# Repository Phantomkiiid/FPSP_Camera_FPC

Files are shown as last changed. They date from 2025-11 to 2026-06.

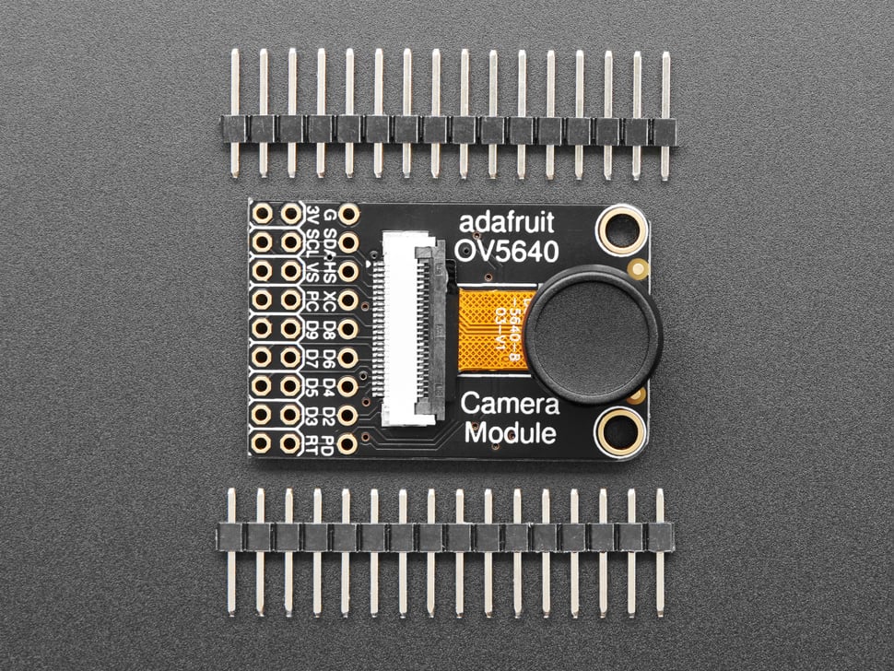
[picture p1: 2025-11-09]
docs/Adafruit-OV5640-Camera-Breakout-PCB-main/assets/5673-06.jpg

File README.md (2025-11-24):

# FPSP_Camera_FPC
This repo contains FPC schematics of the newly developed FPSP camera project on an FPC board, aiming for super-high-speed parallel image processing.

## Repository Structure
| Directory | Use |
| --- | --- |
| archive_old/ | Archived initial design (**not working**) |
| custom_fp/ | Footprint from external libraries |
| docs/ | Documentation gathered from external sources |

## TODO
- [ ] RP2350 Power Supply Layout
- [ ] Add Proper Power Sequencing
- [ ] Source RP2354 A4
- [ ] Source B2B Connector
- [ ] B2B Connector Pinout + Layout
- [ ] HSTX Layout

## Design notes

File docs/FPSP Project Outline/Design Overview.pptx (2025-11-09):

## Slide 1

Design Overview: one processing unit

Industrial CMOS sensor

(front-end integrated)

Options:
Sony: IMX273 / IMX287
OnSemi: python series
Teledyne: EV76C560 / EV76C570

one “pixel”

Vdd

MSPM0C1104 microcontroller

comp flag

global I/O

registers

enable flag

E

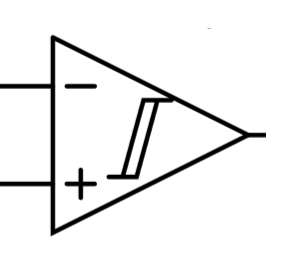
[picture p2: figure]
enter image description here

neighbour I/O & register values

A/D bus

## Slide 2

Design Overview: overall architecture

pixel unit

pixel processor

N pixels

···

···

···

···

···

···

Pixel array

···

···

N pixels

Himax HX6537-A
Pixel Array Microprocessor

···

···

A/D bus 1

···

A/D bus k

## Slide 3

Model | Resolution (pixels) | Pixel Size (µm) | Optical Format | Max Frame Rate (fps) | Output Interface(s) | Notes
Sony IMX273 | 1456 × 1088 (~1.58 MP) | 3.45 × 3.45 | 1/2.9″ (~6.3 mm) | ~226.5 (10-bit mode) | Sub-LVDS / MIPI (varies) | Low-noise, high-speed, common in inspection
Sony IMX287 | 728 × 544 (~0.4 MP) | 6.9 × 6.9 | 1/2.9″ (~6.3 mm) | ~436.9 (10-bit mode) | Sub-LVDS / MIPI (varies) | Large pixels, high sensitivity, good in NIR / low light
OnSemi PYTHON1300 | 1280 × 1024 (1.3 MP) | 4.8 × 4.8 | 1/2″ | ~210 (LVDS) / ~43 (parallel) | LVDS (multi-lane) / parallel | supports ROI, programmable gain, CDS.
OnSemi PYTHON5000 | 2592 × 2048 (~5.3 MP) | 4.8 × 4.8 | ~1″ | Up to ~100 (Zero ROT mode) | LVDS (e.g., 8-lane) | Higher resolution, suited for machine vision with high data bandwidth.
Teledyne EV76C560 | 1280 × 1024 (1.31 MP) | 5.3 × 5.3 | 1/1.8″ | ~60 full res (VGA/cropped >100) | Parallel 10-bit | Dual shutter modes, WDR/HDR, ROI, defect correction.
Teledyne EV76C570 | 1600 × 1200 (~2.0 MP) | 4.5 × 4.5 | 1/1.8″ | ~50 full res | Parallel 10-bit | 2 MP variant, good low-light and dynamic range features.

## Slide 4

Design Overview: overall architecture v2.0

OV5640

···

FPC

DVP

PIO

···

RP2354A

Inter-FPC connection

Strengthened FPC

Pin Header

FPGA board
(pynq / zynq)

PL: data receive
PS: data process

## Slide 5

Layout Overview

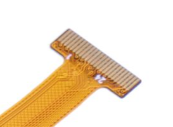
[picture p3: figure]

Main FPC

Strengthened FPC

BUCK/LDO

Pin Header to FPGA

OV5640
(front)

ZIF Connector

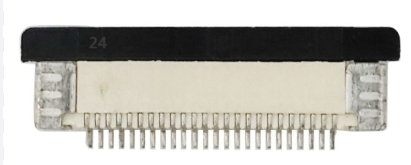
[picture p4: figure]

Vin

···

···

RP2354A
(back)

ASM330LHH
(back)

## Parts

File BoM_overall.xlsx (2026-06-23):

Part Name | Series Number / Description | Quantity | Source | Unit Price (GBP) | Order Code / Mouser No | Link
USB_B_Micro | USB_Micro-B_Molex_47346-0001 | 5 | Farnell | 1.2 | 1568026 | https://uk.farnell.com/molex/47346-0001/micro-usb-conn-2-0-type-b-r-a/dp/1568026
Conn_02x07_Counter_Clockwise | Molex_SlimStack_502426-1430_2x07_P0.40mm_Vertical | 10 | Farnell | 0.868 | 3500584 | https://uk.farnell.com/molex/502426-1430/mezzanine-conn-rcpt-14pos-2row/dp/3500584
Conn_02x07_Counter_Clockwise | Molex_SlimStack_502430-1430_2x07_P0.40mm_Vertical | 10 | Farnell | 0.465 | 3911710 | https://uk.farnell.com/molex/502430-1430/mezzanine-conn-hdr-14pos-2row/dp/3911710
Switch (slide) | CAS-120TA1 | 10 | Farnell | 1.1832 | 2854716 | https://uk.farnell.com/nidec-copal-electronics/cas-120ta/slide-switch-spdt-0-1a-6vdc-smd/dp/2854716
Push Button | PTS526SM15SMTR2 LFS | 10 | Mouser | 0.12 | 611-PTS526SM15SMTR2L | https://www.mouser.co.uk/ProductDetail/CK/PTS526SM15SMTR2-LFS?qs=Imq1NPwxi75LpUh6FiCy2w%3D%3D
SM03B-SRSS-TB | JST_SH_SM03B-SRSS-TB_1x03-1MP_P1.00mm_Horizontal | 5 | Farnell | 0.52 | 1679118 | https://uk.farnell.com/stmicroelectronics/lsm6dsltr/inemo-inertial-module-2-4-8-16g/dp/2761748
IMU | LSM6DSLTR | 5 | Farnell | 7.884 | 4572492 | https://uk.farnell.com/tdk/icm-45686/mems-module-6-axis-1-71v-3-6v/dp/4572492
LDO | TLV73315PDRV | 5 | Mouser | 0.44 | 595-TLV73315PQDRVRQ1 | https://www.mouser.co.uk/ProductDetail/Texas-Instruments/TLV73315PQDRVRQ1?qs=Euq2YPj5ArIsMkihzFWY8w%3D%3D
MCU | RP2354A | 5 | Mouser | 0.751 | 358-SC151113 | https://www.mouser.co.uk/ProductDetail/Raspberry-Pi/SC151113-A4?qs=4dK74SdgGtxoqGOrTUEtvA%3D%3D
Mems | SiT8008BI-13-33E-12.000000G | 5 | Mouser | 0.721 | 788-8008BI1333E12G | https://www.mouser.co.uk/ProductDetail/SiTime/SiT8008BI-13-33E-12.000000G?qs=dMZC7um9hO8fSmv9H8HgEQ%3D%3D
FPC socket | molex 52435-2471 | 10 | Farnell | 2.352 | 2396220 | https://uk.farnell.com/molex/52435-2471/connector-ffc-fpc-24pos-1row-0/dp/2396220
Camera | OV5640 - 24pin fpc | 2 | Ali | N/A | N/A | https://www.aliexpress.com/p/tesla-landing/index.html?UTABTest=aliabtest125094_24784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
2.54mm pin header: from UCL
0603 R&C: from UCL

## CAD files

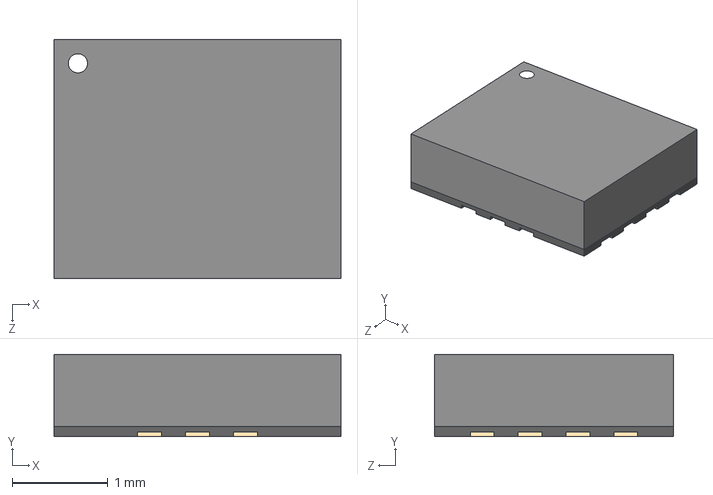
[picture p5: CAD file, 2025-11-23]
custom_fp/ICM_45686/ICM-45686.step
3.00 x 0.86 x 2.50 mm

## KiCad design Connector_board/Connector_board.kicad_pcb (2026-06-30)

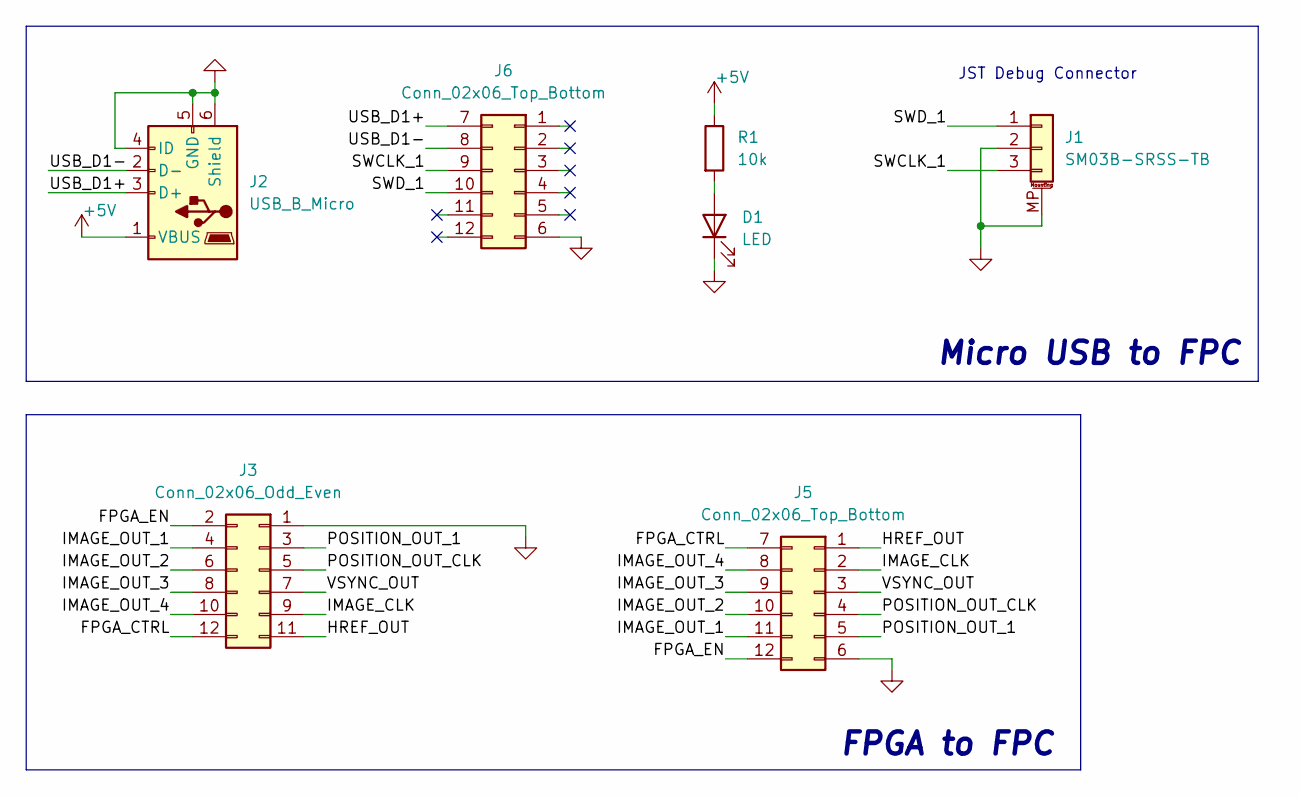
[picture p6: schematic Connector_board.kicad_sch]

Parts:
D1: LED; D_0603_1608Metric
J1: SM03B-SRSS-TB; JST_SH_SM03B-SRSS-TB_1x03-1MP_P1.00mm_Horizontal
J2: USB_B_Micro; USB_Micro-B_Molex_47346-0001
J3: Conn_02x06_Odd_Even; PinHeader_2x06_P2.54mm_Vertical
J5, J6: Conn_02x06_Top_Bottom; CON_5035521222
R1: 10k; R_0603_1608Metric_Pad0.98x0.95mm_HandSolder

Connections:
+5V: J2.1 (VBUS), R1.1
/FPGA_CTRL: J3.12, J5.7
/FPGA_EN: J3.2, J5.12
/HREF_OUT: J3.11, J5.1
/IMAGE_CLK: J3.9, J5.2
/IMAGE_OUT_1: J3.4, J5.11
/IMAGE_OUT_2: J3.6, J5.10
/IMAGE_OUT_3: J3.8, J5.9
/IMAGE_OUT_4: J3.10, J5.8
/POSITION_OUT_1: J3.3, J5.5
/POSITION_OUT_CLK: J3.5, J5.4
/SWCLK_1: J1.3, J6.9
/SWD_1: J1.1, J6.10
/USB_D1+: J2.3 (D+), J6.7
/USB_D1-: J2.2 (D-), J6.8
/VSYNC_OUT: J3.7, J5.3
GND: D1.1 (K), J1.2, J1.MP (MountPin), J2.4 (ID), J2.5 (GND), J2.6 (Shield), J3.1, J5.6, J6.6
unnamed: D1.2 (A), R1.2

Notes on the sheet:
FPGA to FPC
Micro USB to FPC
JST Debug Connector

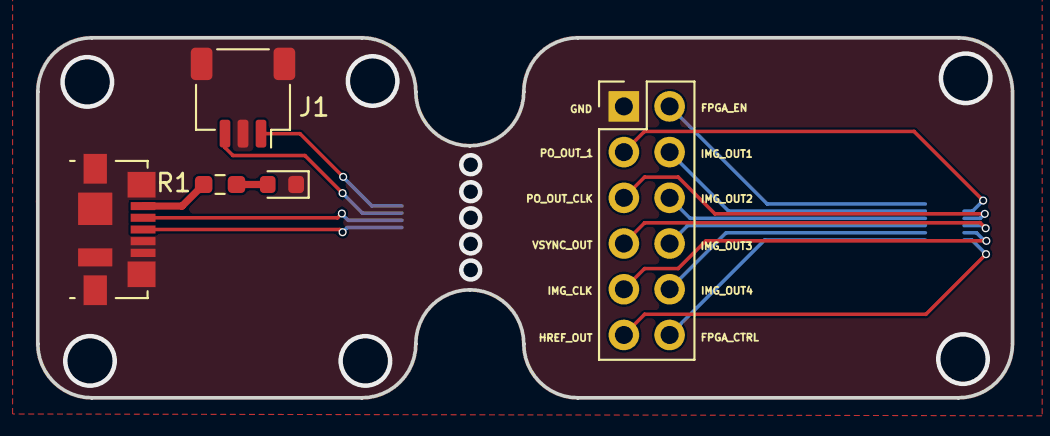
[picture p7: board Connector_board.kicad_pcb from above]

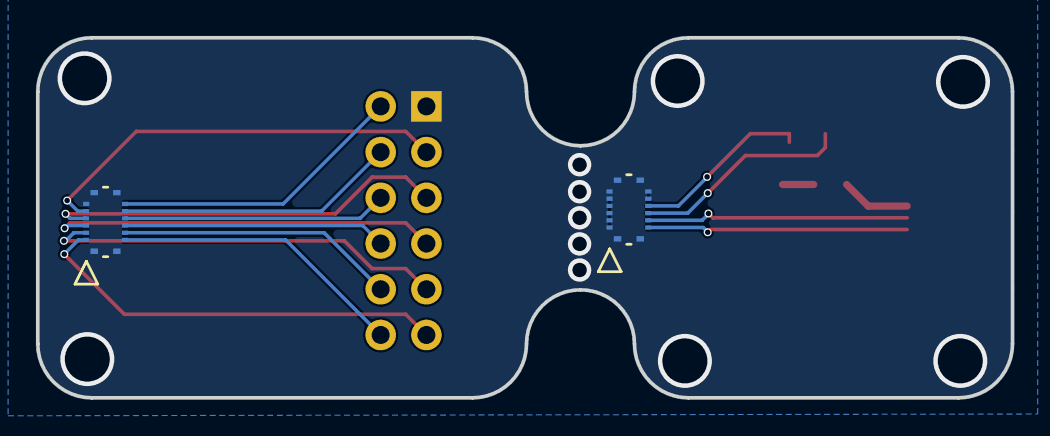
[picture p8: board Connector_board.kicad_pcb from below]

Board: 2 copper layers, 54.2 x 20.0 mm, 7 parts (2 on the bottom side), 18 nets.

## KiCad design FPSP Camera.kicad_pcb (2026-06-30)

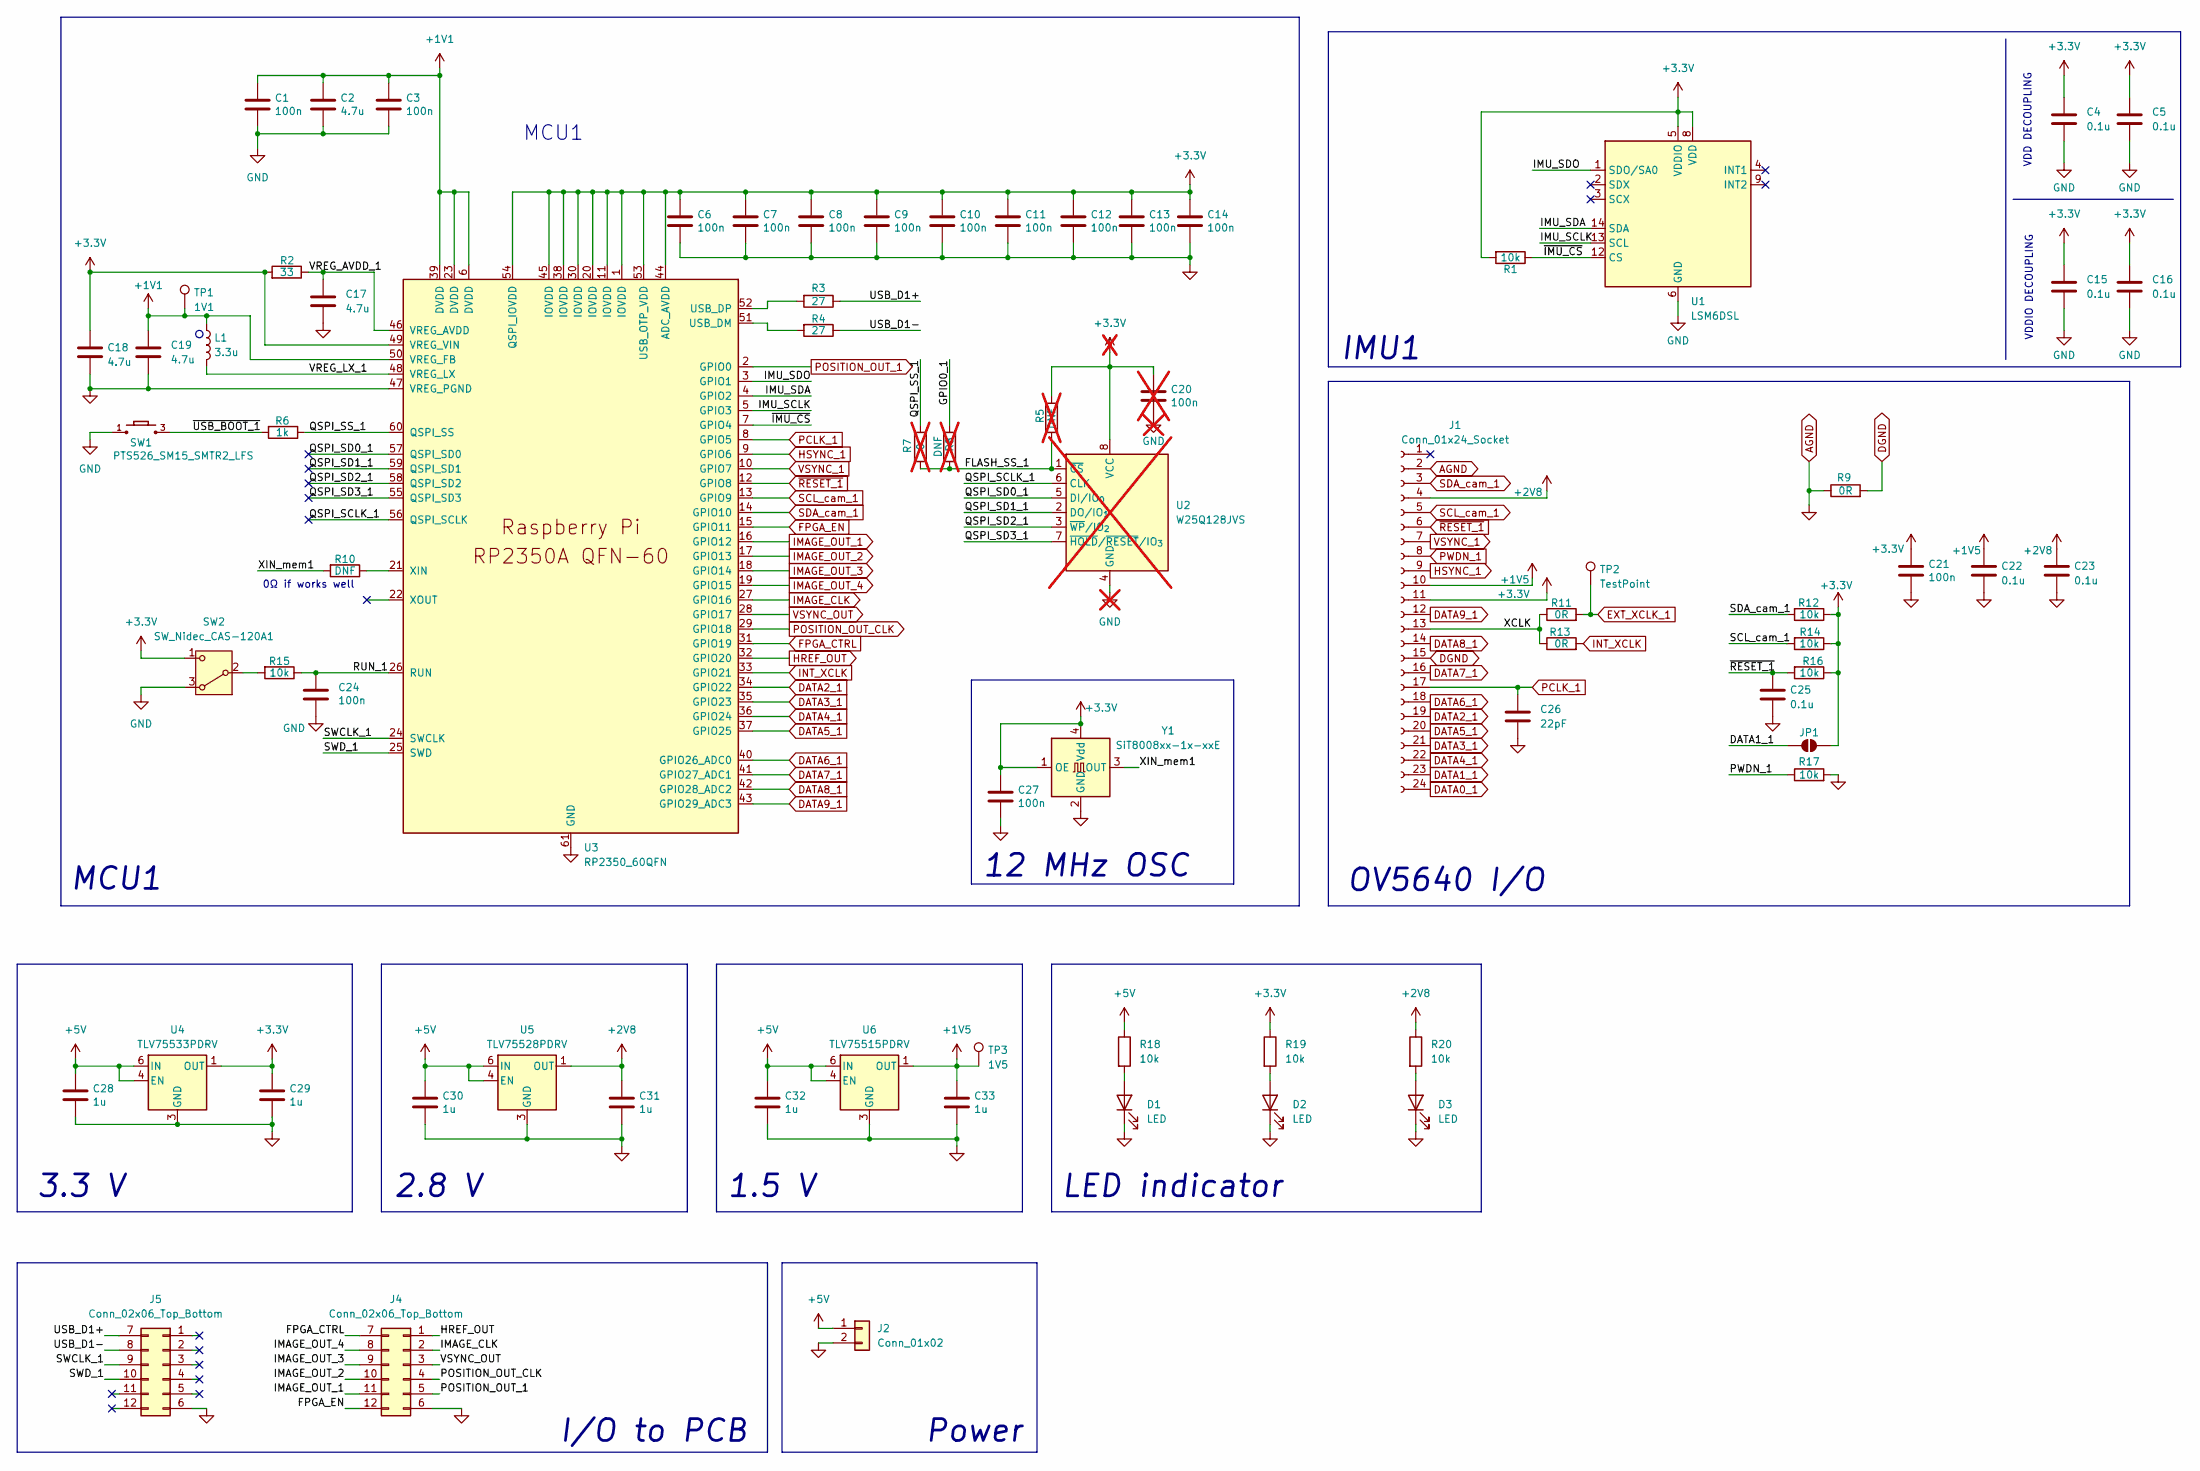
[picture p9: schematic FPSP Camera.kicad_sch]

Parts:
C1, C3, C6, C7, C8, C9, C10, C11, C12, C13, C14, C21, C24, C27: 100n; C_0402_1005Metric
C2, C17, C18, C19: 4.7u; C_0402_1005Metric
C4, C5, C15, C16, C22, C23, C25: 0.1u; C_0402_1005Metric
C20: 100n; C_0603_1608Metric_Pad1.08x0.95mm_HandSolder; not fitted
C26: 22pF; C_0402_1005Metric
C28, C29, C30, C31, C32, C33: 1u; C_0402_1005Metric
D1, D2, D3: LED; D_0603_1608Metric
J1: Conn_01x24_Socket; MOLEX_52435-2471
J2: Conn_01x02; PinHeader_1x02_P2.54mm_Vertical
J4, J5: Conn_02x06_Top_Bottom; CON_5035521222
JP1: SolderJumper_2_Open; SolderJumper-2_P1.3mm_Open_RoundedPad1.0x1.5mm
L1: 3.3u; L_pol_2016
R1: 10k; R_0402_1005Metric_Pad0.72x0.64mm_HandSolder
R2: 33; R_0402_1005Metric
R3, R4: 27; R_0402_1005Metric
R5, R8: DNF; R_0603_1608Metric_Pad0.98x0.95mm_HandSolder; not fitted
R6: 1k; R_0402_1005Metric
R7: 0; R_0603_1608Metric_Pad0.98x0.95mm_HandSolder; not fitted
R9, R11, R13: 0R; R_0402_1005Metric
R10: DNF; R_0402_1005Metric
R12, R14, R15, R16, R17, R18, R19, R20: 10k; R_0402_1005Metric
SW1: PTS526_SM15_SMTR2_LFS; PTS526SM15SMTR2LFS; MOUSER_PART_NUMBER 611-PTS526SM15SMTR2L
SW2: SW_Nidec_CAS-120A1; Nidec_Copal_CAS-120A
TP1: 1V1; TestPoint_Pad_D1.0mm
TP2: TestPoint; TestPoint_Pad_D1.0mm
TP3: 1V5; TestPoint_Pad_D1.0mm
U1: LSM6DSL; LGA-14_3x2.5mm_P0.5mm_LayoutBorder3x4y
U2: W25Q128JVS; SOIC-8_5.3x5.3mm_P1.27mm; not fitted
U3: RP2350_60QFN; RP2350-QFN-60-1EP_7x7_P0.4mm_EP3.4x3.4mm_ThermalVias
U4: TLV75533PDRV; WSON-6-1EP_2x2mm_P0.65mm_EP1x1.6mm
U5: TLV75528PDRV; WSON-6-1EP_2x2mm_P0.65mm_EP1x1.6mm
U6: TLV75515PDRV; WSON-6-1EP_2x2mm_P0.65mm_EP1x1.6mm
Y1: SiT8008xx-1x-xxE; Oscillator_SMD_SiT_PQFN-4Pin_2.5x2.0mm

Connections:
+1V1: C1.1, C2.1, C3.1, C19.1, L1.1, TP1.1 (1_1), U3.6 (DVDD), U3.23 (DVDD), U3.39 (DVDD), U3.50 (VREG_FB)
+1V5: C22.1, C33.1, J1.10, TP3.1 (1_1), U6.1 (OUT)
+2V8: C23.1, C31.1, J1.4, R20.1, U5.1 (OUT)
+3.3V: C4.1, C5.1, C6.1, C7.1, C8.1, C9.1, C10.1, C11.1, C12.1, C13.1, C14.1, C15.1, C16.1, C18.1, C20.1, C21.1, C27.1, C29.1, J1.11, JP1.2 (B), R1.2, R2.2, R5.1, R12.1, R14.1, R16.1, R19.1, SW2.1 (C), U1.5 (VDDIO), U1.8 (VDD), U2.8 (VCC), U3.1 (IOVDD), U3.11 (IOVDD), U3.20 (IOVDD), U3.30 (IOVDD), U3.38 (IOVDD), U3.44 (ADC_AVDD), U3.45 (IOVDD), U3.49 (VREG_VIN), U3.53 (USB_OTP_VDD), U3.54 (QSPI_IOVDD), U4.1 (OUT), Y1.1 (OE), Y1.4 (Vdd)
+5V: C28.1, C30.1, C32.1, J2.1, R18.1, U4.4 (EN), U4.6 (IN), U5.4 (EN), U5.6 (IN), U6.4 (EN), U6.6 (IN)
/IMU_SCLK: U1.13 (SCL), U3.5 (GPIO3)
/IMU_SDA: U1.14 (SDA), U3.4 (GPIO2)
/IMU_SDO: U1.1 (SDO/SA0), U3.3 (GPIO1)
/QSPI_SCLK_1: U2.6 (CLK), U3.56 (QSPI_SCLK)
/QSPI_SD0_1: U2.5 (DI/IO_{0}), U3.57 (QSPI_SD0)
/QSPI_SD1_1: U2.2 (DO/IO_{1}), U3.59 (QSPI_SD1)
/QSPI_SD2_1: U2.3 (~WP/IO_{2}), U3.58 (QSPI_SD2)
/QSPI_SD3_1: U2.7 (~HOLD/~RESET/IO_{3}), U3.55 (QSPI_SD3)
/QSPI_SS_1: R6.1, R7.2, U3.60 (QSPI_SS)
/RUN_1: C24.1, R15.1, U3.26 (RUN)
/SWCLK_1: J5.9, U3.24 (SWCLK)
/SWD_1: J5.10, U3.25 (SWD)
/USB_D1+: J5.7, R3.1
/USB_D1-: J5.8, R4.1
/VREG_AVDD_1: C17.1, R2.1, U3.46 (VREG_AVDD)
/VREG_LX_1: L1.2, U3.48 (VREG_LX)
/XCLK: J1.13, R11.1, R13.1
/XIN_mem1: R10.2, Y1.3 (OUT)
/~IMU_CS: R1.1, U1.12 (CS), U3.7 (GPIO4)
/~USB_BOOT_1: R6.2, SW1.3, SW1.4
AGND: C1.2, C2.2, C3.2, C4.2, C5.2, C6.2, C7.2, C8.2, C9.2, C10.2, C11.2, C12.2, C13.2, C14.2, C15.2, C16.2, C17.2, C18.2, C19.2, C20.2, C21.2, C22.2, C23.2, C24.2, C25.2, C26.2, C27.2, C28.2, C29.2, C30.2, C31.2, C32.2, C33.2, D1.1 (K), D2.1 (K), D3.1 (K), J1.2, J1.MP, J2.2, J4.6, J5.6, R9.1, R17.2, SW1.1, SW1.2, SW2.3 (A), U1.6 (GND), U1.7 (GND), U2.4 (GND), U3.47 (VREG_PGND), U3.61 (GND), U4.3 (GND), U4.7 (GND), U5.3 (GND), U5.7 (GND), U6.3 (GND), U6.7 (GND), Y1.2 (GND)
DATA0_1: J1.24
DATA1_1: J1.23, JP1.1 (A)
DATA2_1: J1.19, U3.34 (GPIO22)
DATA3_1: J1.21, U3.35 (GPIO23)
DATA4_1: J1.22, U3.36 (GPIO24)
DATA5_1: J1.20, U3.37 (GPIO25)
DATA6_1: J1.18, U3.40 (GPIO26_ADC0)
DATA7_1: J1.16, U3.41 (GPIO27_ADC1)
DATA8_1: J1.14, U3.42 (GPIO28_ADC2)
DATA9_1: J1.12, U3.43 (GPIO29_ADC3)
DGND: J1.15, R9.2
EXT_XCLK_1: R11.2, TP2.1 (1_1)
FPGA_CTRL: J4.7, U3.31 (GPIO19)
FPGA_EN: J4.12, U3.15 (GPIO11)
HREF_OUT: J4.1, U3.32 (GPIO20)
HSYNC_1: J1.9, U3.9 (GPIO6)
IMAGE_CLK: J4.2, U3.27 (GPIO16)
IMAGE_OUT_1: J4.11, U3.16 (GPIO12)
IMAGE_OUT_2: J4.10, U3.17 (GPIO13)
IMAGE_OUT_3: J4.9, U3.18 (GPIO14)
IMAGE_OUT_4: J4.8, U3.19 (GPIO15)
INT_XCLK: R13.2, U3.33 (GPIO21)
unnamed: D1.2 (A), R18.2
unnamed: D2.2 (A), R19.2
unnamed: D3.2 (A), R20.2
unnamed: R5.2, R7.1, R8.1, U2.1 (~CS)
unnamed: R15.2, SW2.2 (B)
unnamed: R4.2, U3.51 (USB_DM)
unnamed: R3.2, U3.52 (USB_DP)
unnamed: R10.1, U3.21 (XIN)
PCLK_1: C26.1, J1.17, U3.8 (GPIO5)
POSITION_OUT_1: J4.5, U3.2 (GPIO0)
POSITION_OUT_CLK: J4.4, U3.29 (GPIO18)
PWDN_1: J1.8, R17.1
SCL_cam_1: J1.5, R14.2, U3.13 (GPIO9)
SDA_cam_1: J1.3, R12.2, U3.14 (GPIO10)
VSYNC_1: J1.7, U3.10 (GPIO7)
VSYNC_OUT: J4.3, U3.28 (GPIO17)
~RESET_1: C25.1, J1.6, R16.2, U3.12 (GPIO8)

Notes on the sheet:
I/O to PCB
0Ω if works well
IMU1
3.3 V
MCU1
12 MHz OSC
Power
2.8 V
VDD DECOUPLING
LED indicator
1.5 V
VDDIO DECOUPLING
OV5640 I/O

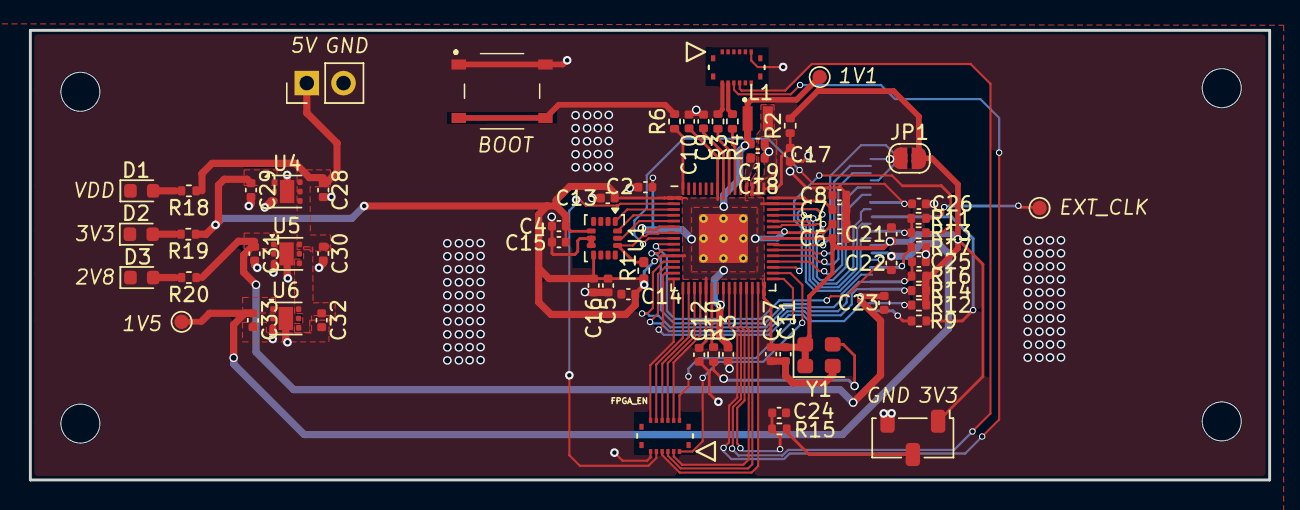
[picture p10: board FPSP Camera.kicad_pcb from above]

Board: 4 copper layers, 85.7 x 31.1 mm, 73 parts (1 on the bottom side), 58 nets.

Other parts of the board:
H1, H2, H3, H4: MountingHole; MountingHole_2.7mm_M2.5

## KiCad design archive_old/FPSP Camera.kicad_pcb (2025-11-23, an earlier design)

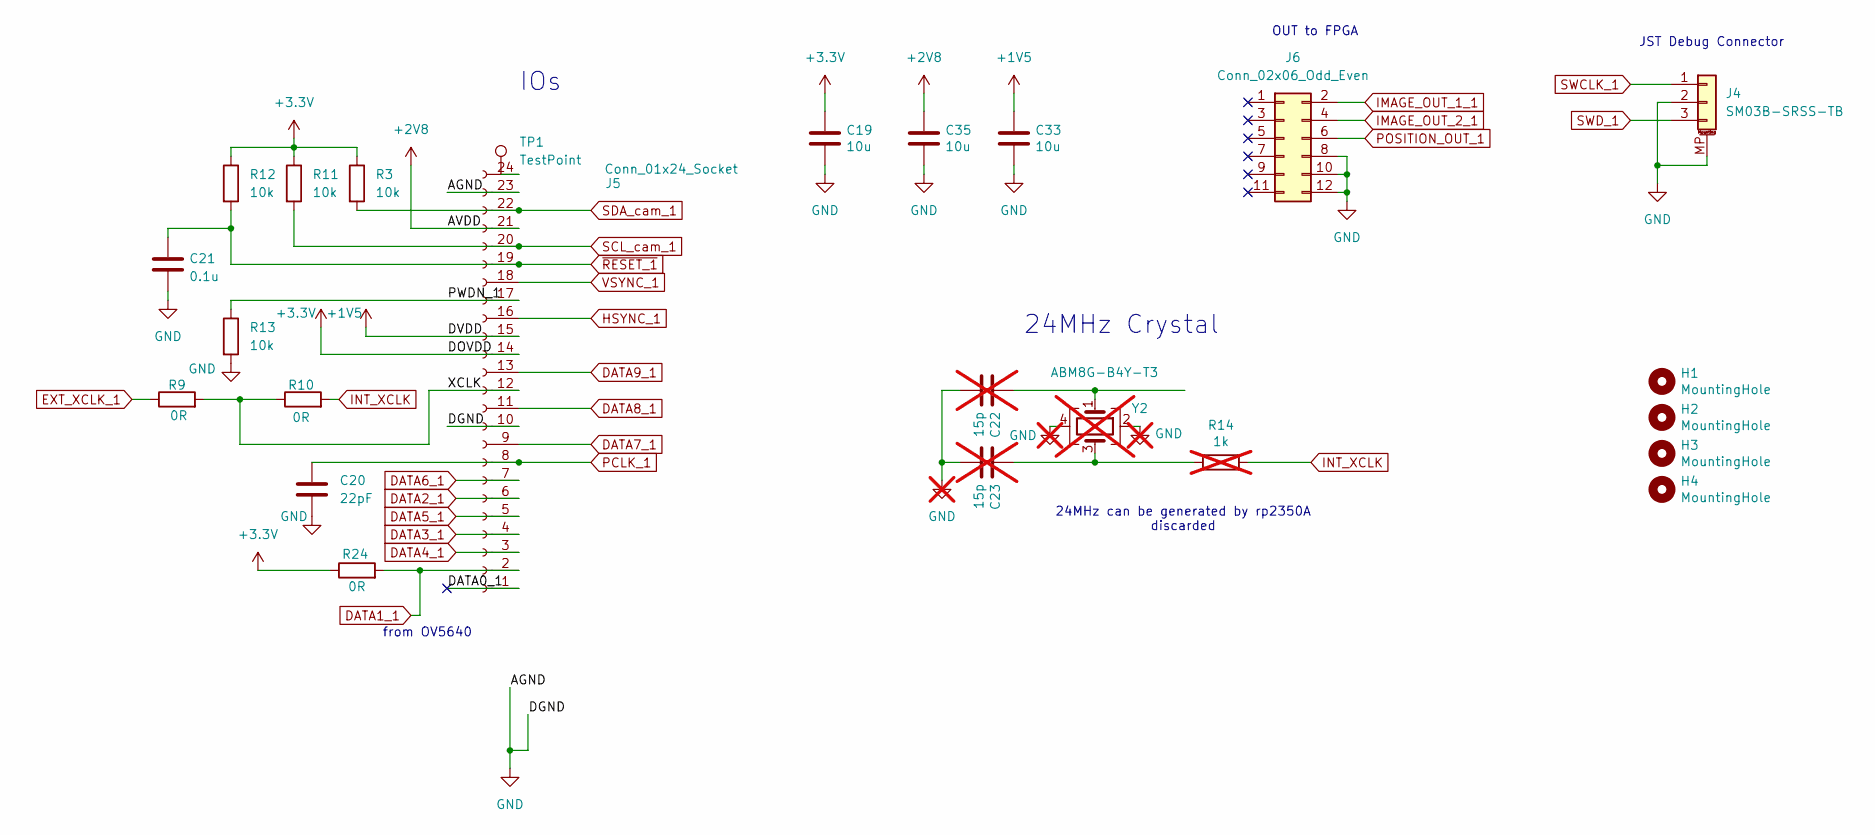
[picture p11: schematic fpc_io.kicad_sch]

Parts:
C19, C33, C35: 10u; C_0603_1608Metric_Pad1.08x0.95mm_HandSolder
C20: 22pF; C_0603_1608Metric_Pad1.08x0.95mm_HandSolder
C21: 0.1u; C_0603_1608Metric_Pad1.08x0.95mm_HandSolder
C22, C23: 15p; C_0603_1608Metric_Pad1.08x0.95mm_HandSolder; not fitted
H1, H2, H3, H4: MountingHole; MountingHole_2.7mm_M2.5
J4: SM03B-SRSS-TB; JST_SH_SM03B-SRSS-TB_1x03-1MP_P1.00mm_Horizontal
J5: Conn_01x24_Socket; TE_2-84952-4_1x24-1MP_P1.0mm_Horizontal
J6: Conn_02x06_Odd_Even; PinHeader_2x06_P2.54mm_Vertical
R3, R11, R12, R13: 10k; R_0603_1608Metric_Pad0.98x0.95mm_HandSolder
R9, R10, R24: 0R; R_0603_1608Metric_Pad0.98x0.95mm_HandSolder
R14: 1k; R_0603_1608Metric_Pad0.98x0.95mm_HandSolder; not fitted
TP1: TestPoint; TestPoint_Pad_D1.0mm
Y2: ABM8G-B4Y-T3; Crystal_SMD_3225-4Pin_3.2x2.5mm; not fitted

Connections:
+1V5: C33.1, J5.15; also elsewhere on the board
+2V8: C35.1, J5.21; also elsewhere on the board
+3.3V: C19.1, J5.14, R3.1, R11.1, R12.1, R24.1; also elsewhere on the board
/IOs/DATA0_1: J5.1
/IOs/PWDN_1: J5.17, R13.1
/IOs/XCLK: J5.12, R9.2, R10.1
DATA1_1: J5.2, R24.2
DATA2_1: J5.6; also elsewhere on the board
DATA3_1: J5.4; also elsewhere on the board
DATA4_1: J5.3; also elsewhere on the board
DATA5_1: J5.5; also elsewhere on the board
DATA6_1: J5.7; also elsewhere on the board
DATA7_1: J5.9; also elsewhere on the board
DATA8_1: J5.11; also elsewhere on the board
DATA9_1: J5.13; also elsewhere on the board
EXT_XCLK_1: R9.1; also elsewhere on the board
GND: C19.2, C20.2, C21.2, C22.2, C23.2, C33.2, C35.2, J4.2, J4.MP (MountPin), J5.10, J5.23, J6.8, J6.10, J6.12, R13.2, Y2.2, Y2.4; also elsewhere on the board
HSYNC_1: J5.16; also elsewhere on the board
IMAGE_OUT_1_1: J6.2; also elsewhere on the board
IMAGE_OUT_2_1: J6.4; also elsewhere on the board
INT_XCLK: R10.2, R14.1; also elsewhere on the board
unnamed: C22.1, Y2.1
unnamed: C23.1, R14.2, Y2.3
unnamed: J5.24, TP1.1
PCLK_1: C20.1, J5.8; also elsewhere on the board
POSITION_OUT_1: J6.6; also elsewhere on the board
SCL_cam_1: J5.20, R11.2; also elsewhere on the board
SDA_cam_1: J5.22, R3.2; also elsewhere on the board
SWCLK_1: J4.1; also elsewhere on the board
SWD_1: J4.3; also elsewhere on the board
VSYNC_1: J5.18; also elsewhere on the board
~RESET_1: C21.1, J5.19, R12.2; also elsewhere on the board

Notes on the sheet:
from OV5640
24MHz Crystal
24MHz can be generated by rp2350A discarded
OUT to FPGA
IOs
JST Debug Connector

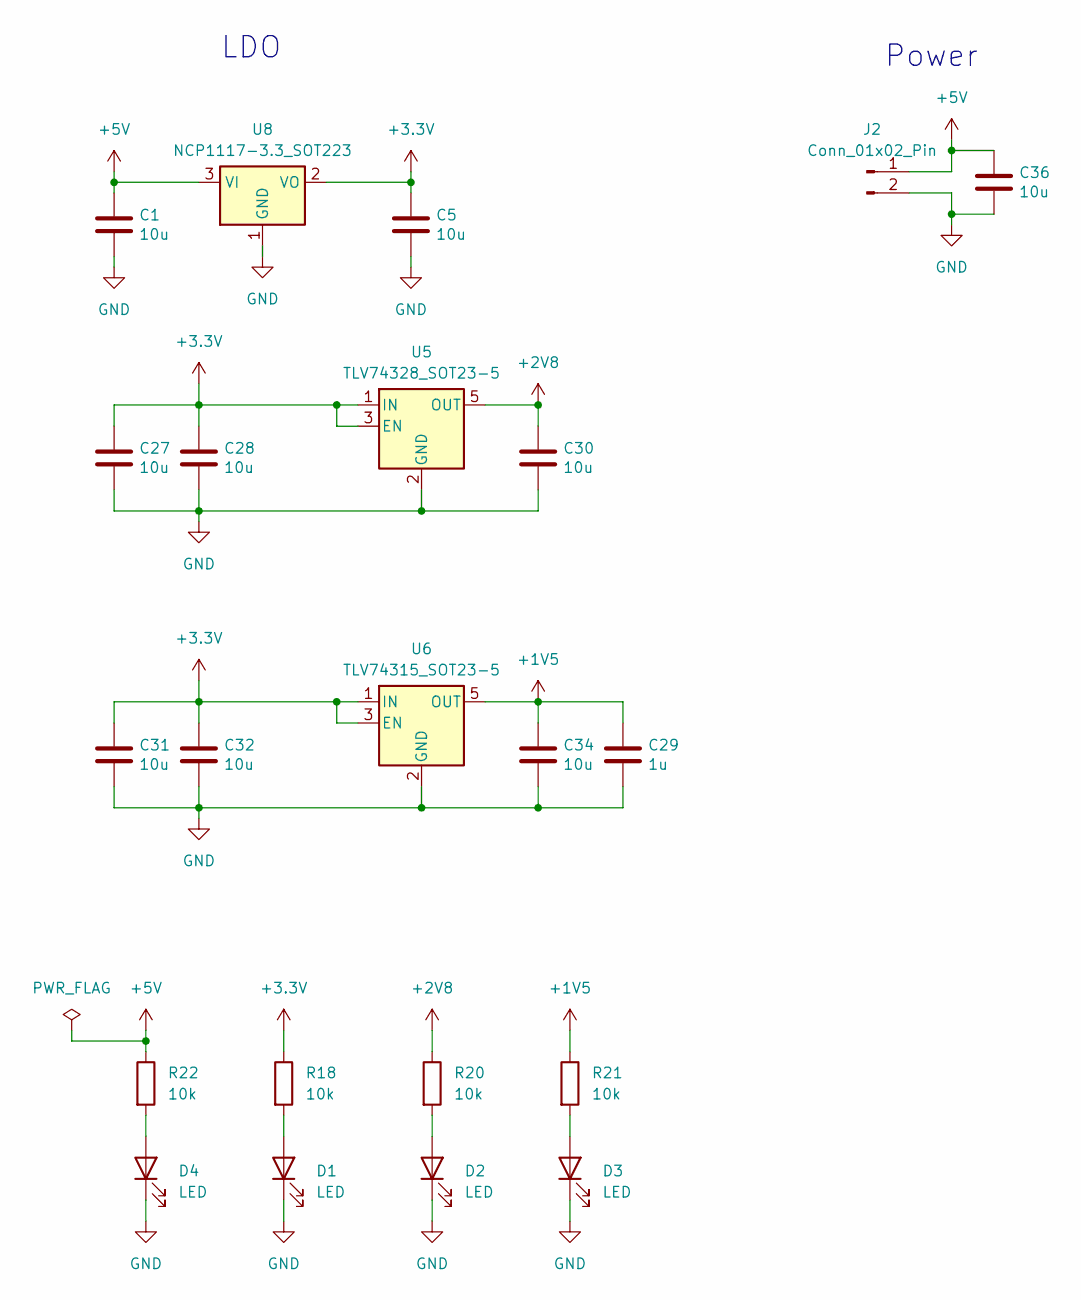
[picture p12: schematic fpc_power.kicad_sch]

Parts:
C1, C5, C27, C28, C30, C31, C32, C34: 10u; C_0603_1608Metric_Pad1.08x0.95mm_HandSolder
C29: 1u; C_0603_1608Metric_Pad1.08x0.95mm_HandSolder
C36: 10u; CP_Radial_D8.0mm_P2.50mm
D1, D2, D3, D4: LED; D_0603_1608Metric
J2: Conn_01x02_Pin; TerminalBlock_MaiXu_MX126-5.0-02P_1x02_P5.00mm
R18, R20, R21, R22: 10k; R_0603_1608Metric_Pad0.98x0.95mm_HandSolder
U5: TLV74328_SOT23-5; SOT-23-5
U6: TLV74315_SOT23-5; SOT-23-5
U8: NCP1117-3.3_SOT223; SOT-223-3_TabPin2

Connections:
+1V5: C29.1, C34.1, R21.1, U6.5 (OUT); also elsewhere on the board
+2V8: C30.1, R20.1, U5.5 (OUT); also elsewhere on the board
+3.3V: C5.1, C27.1, C28.1, C31.1, C32.1, R18.1, U5.1 (IN), U5.3 (EN), U6.1 (IN), U6.3 (EN), U8.2 (VO); also elsewhere on the board
+5V: C1.1, C36.1, J2.1, R22.1, U8.3 (VI)
GND: C1.2, C5.2, C27.2, C28.2, C29.2, C30.2, C31.2, C32.2, C34.2, C36.2, D1.1 (K), D2.1 (K), D3.1 (K), D4.1 (K), J2.2, U5.2 (GND), U6.2 (GND), U8.1 (GND); also elsewhere on the board
unnamed: D1.2 (A), R18.2
unnamed: D2.2 (A), R20.2
unnamed: D3.2 (A), R21.2
unnamed: D4.2 (A), R22.2

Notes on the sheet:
LDO
Power

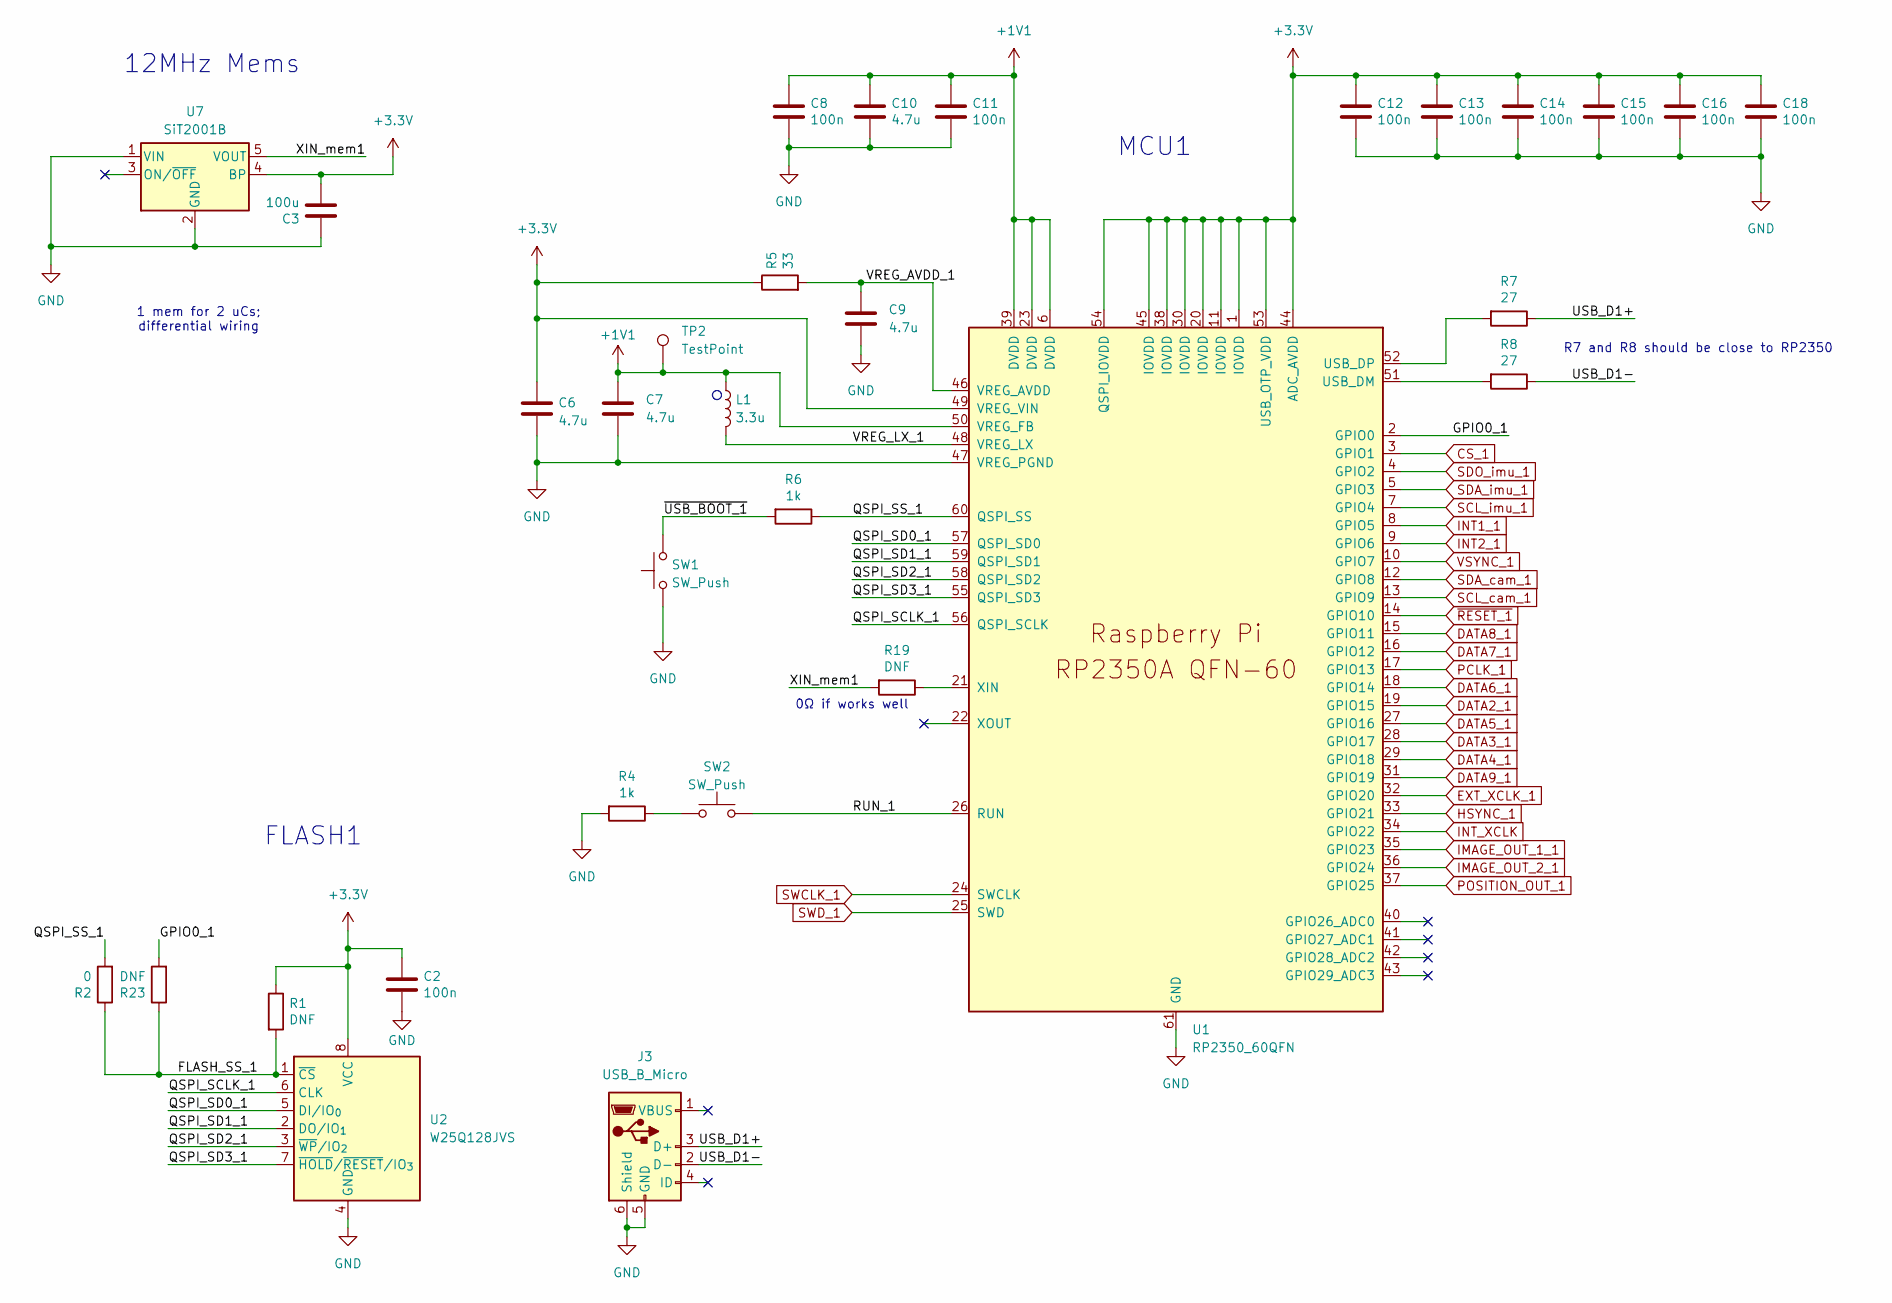
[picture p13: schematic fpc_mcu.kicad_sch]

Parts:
C2, C8, C11, C12, C13, C14, C15, C16, C18: 100n; C_0603_1608Metric_Pad1.08x0.95mm_HandSolder
C3: 100u; C_0603_1608Metric_Pad1.08x0.95mm_HandSolder
C6, C7, C9, C10: 4.7u; C_0603_1608Metric_Pad1.08x0.95mm_HandSolder
J3: USB_B_Micro; USB_Micro-B_Amphenol_10103594-0001LF_Horizontal_modified
L1: 3.3u; L_pol_2016
R1, R19, R23: DNF; R_0603_1608Metric_Pad0.98x0.95mm_HandSolder
R2: 0; R_0603_1608Metric_Pad0.98x0.95mm_HandSolder
R4, R6: 1k; R_0603_1608Metric_Pad0.98x0.95mm_HandSolder
R5: 33; R_0603_1608Metric_Pad0.98x0.95mm_HandSolder
R7, R8: 27; R_0603_1608Metric_Pad0.98x0.95mm_HandSolder
SW1, SW2: SW_Push; SW_Push_1P1T_NO_Vertical_Wuerth_434133025816
TP2: TestPoint; TestPoint_Pad_D1.0mm
U1: RP2350_60QFN; RP2350-QFN-60-1EP_7x7_P0.4mm_EP3.4x3.4mm_ThermalVias
U2: W25Q128JVS; SOIC-8_5.3x5.3mm_P1.27mm
U7: SiT2001B; SOT-23-5

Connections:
+1V1: C7.1, C8.1, C10.1, C11.1, L1.1, TP2.1, U1.6 (DVDD), U1.23 (DVDD), U1.39 (DVDD), U1.50 (VREG_FB)
+3.3V: C2.1, C3.2, C6.1, C12.1, C13.1, C14.1, C15.1, C16.1, C18.1, R1.1, R5.1, U1.1 (IOVDD), U1.11 (IOVDD), U1.20 (IOVDD), U1.30 (IOVDD), U1.38 (IOVDD), U1.44 (ADC_AVDD), U1.45 (IOVDD), U1.49 (VREG_VIN), U1.53 (USB_OTP_VDD), U1.54 (QSPI_IOVDD), U2.8 (VCC), U7.4 (BP); also elsewhere on the board
/MCU/FLASH_SS_1: R1.2, R2.1, R23.1, U2.1 (~CS)
/MCU/GPIO0_1: R23.2, U1.2 (GPIO0)
/MCU/QSPI_SCLK_1: U1.56 (QSPI_SCLK), U2.6 (CLK)
/MCU/QSPI_SD0_1: U1.57 (QSPI_SD0), U2.5 (DI/IO_{0})
/MCU/QSPI_SD1_1: U1.59 (QSPI_SD1), U2.2 (DO/IO_{1})
/MCU/QSPI_SD2_1: U1.58 (QSPI_SD2), U2.3 (~WP/IO_{2})
/MCU/QSPI_SD3_1: U1.55 (QSPI_SD3), U2.7 (~HOLD/~RESET/IO_{3})
/MCU/QSPI_SS_1: R2.2, R6.1, U1.60 (QSPI_SS)
/MCU/RUN_1: SW2.2, U1.26 (RUN)
/MCU/USB_D1+: J3.3 (D+), R7.1
/MCU/USB_D1-: J3.2 (D-), R8.1
/MCU/VREG_AVDD_1: C9.1, R5.2, U1.46 (VREG_AVDD)
/MCU/VREG_LX_1: L1.2, U1.48 (VREG_LX)
/MCU/XIN_mem1: R19.2, U7.5 (VOUT)
/MCU/~USB_BOOT_1: R6.2, SW1.2
CS_1: U1.3 (GPIO1); also elsewhere on the board
DATA2_1: U1.19 (GPIO15); also elsewhere on the board
DATA3_1: U1.28 (GPIO17); also elsewhere on the board
DATA4_1: U1.29 (GPIO18); also elsewhere on the board
DATA5_1: U1.27 (GPIO16); also elsewhere on the board
DATA6_1: U1.18 (GPIO14); also elsewhere on the board
DATA7_1: U1.16 (GPIO12); also elsewhere on the board
DATA8_1: U1.15 (GPIO11); also elsewhere on the board
DATA9_1: U1.31 (GPIO19); also elsewhere on the board
EXT_XCLK_1: U1.32 (GPIO20); also elsewhere on the board
GND: C2.2, C3.1, C6.2, C7.2, C8.2, C9.2, C10.2, C11.2, C12.2, C13.2, C14.2, C15.2, C16.2, C18.2, J3.5 (GND), J3.6 (Shield), R4.2, SW1.1, U1.47 (VREG_PGND), U1.61 (GND), U2.4 (GND), U7.1 (VIN), U7.2 (GND); also elsewhere on the board
HSYNC_1: U1.33 (GPIO21); also elsewhere on the board
IMAGE_OUT_1_1: U1.35 (GPIO23); also elsewhere on the board
IMAGE_OUT_2_1: U1.36 (GPIO24); also elsewhere on the board
INT1_1: U1.8 (GPIO5); also elsewhere on the board
INT2_1: U1.9 (GPIO6); also elsewhere on the board
INT_XCLK: U1.34 (GPIO22); also elsewhere on the board
unnamed: R4.1, SW2.1
unnamed: R8.2, U1.51 (USB_DM)
unnamed: R7.2, U1.52 (USB_DP)
unnamed: R19.1, U1.21 (XIN)
PCLK_1: U1.17 (GPIO13); also elsewhere on the board
POSITION_OUT_1: U1.37 (GPIO25); also elsewhere on the board
SCL_cam_1: U1.13 (GPIO9); also elsewhere on the board
SCL_imu_1: U1.7 (GPIO4); also elsewhere on the board
SDA_cam_1: U1.12 (GPIO8); also elsewhere on the board
SDA_imu_1: U1.5 (GPIO3); also elsewhere on the board
SDO_imu_1: U1.4 (GPIO2); also elsewhere on the board
SWCLK_1: U1.24 (SWCLK); also elsewhere on the board
SWD_1: U1.25 (SWD); also elsewhere on the board
VSYNC_1: U1.10 (GPIO7); also elsewhere on the board
~RESET_1: U1.14 (GPIO10); also elsewhere on the board

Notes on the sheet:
0Ω if works well
MCU1
FLASH1
12MHz Mems
R7 and R8 should be close to RP2350
1 mem for 2 uCs; differential wiring

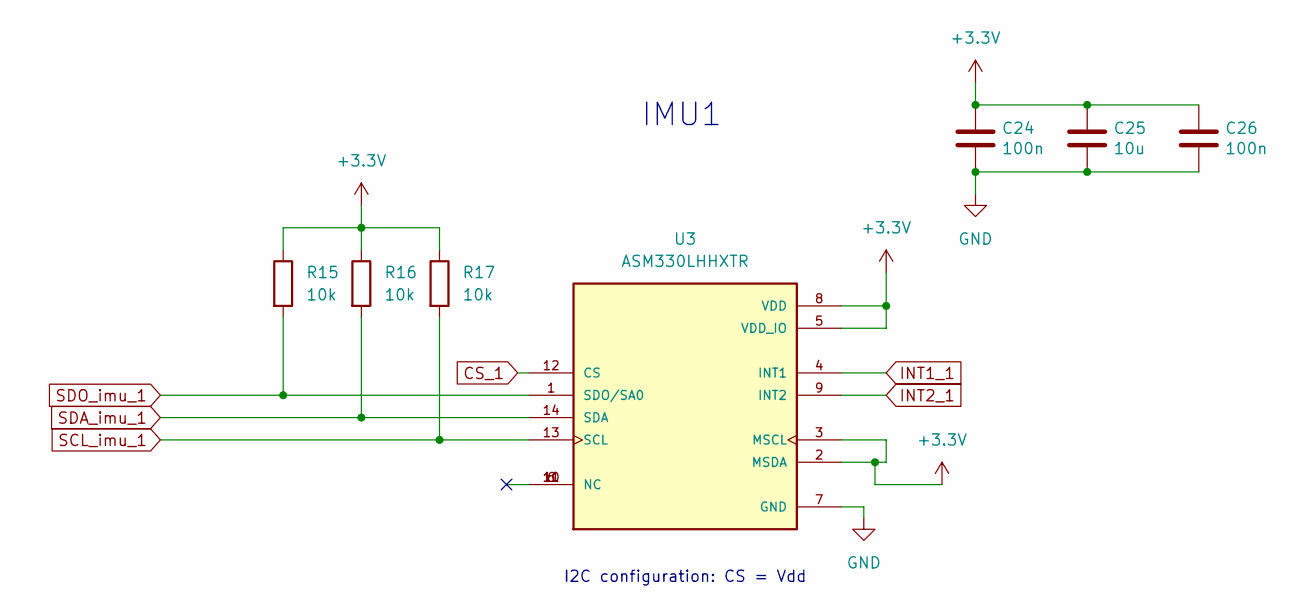
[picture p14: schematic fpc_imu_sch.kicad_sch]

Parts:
C24, C26: 100n; C_0603_1608Metric_Pad1.08x0.95mm_HandSolder
C25: 10u; C_0603_1608Metric_Pad1.08x0.95mm_HandSolder
R15, R16, R17: 10k; R_0603_1608Metric_Pad0.98x0.95mm_HandSolder
U3: ASM330LHHXTR; XDCR_ASM330LHHXTR; PARTREV 8

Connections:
+3.3V: C24.1, C25.1, C26.1, R15.1, R16.1, R17.1, U3.2 (MSDA), U3.3 (MSCL), U3.5 (VDD_IO), U3.8 (VDD); also elsewhere on the board
CS_1: U3.12 (CS); also elsewhere on the board
GND: C24.2, C25.2, C26.2, U3.7 (GND); also elsewhere on the board
INT1_1: U3.4 (INT1); also elsewhere on the board
INT2_1: U3.9 (INT2); also elsewhere on the board
SCL_imu_1: R17.2, U3.13 (SCL); also elsewhere on the board
SDA_imu_1: R16.2, U3.14 (SDA); also elsewhere on the board
SDO_imu_1: R15.2, U3.1 (SDO/SA0); also elsewhere on the board

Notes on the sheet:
I2C configuration: CS = Vdd
IMU1

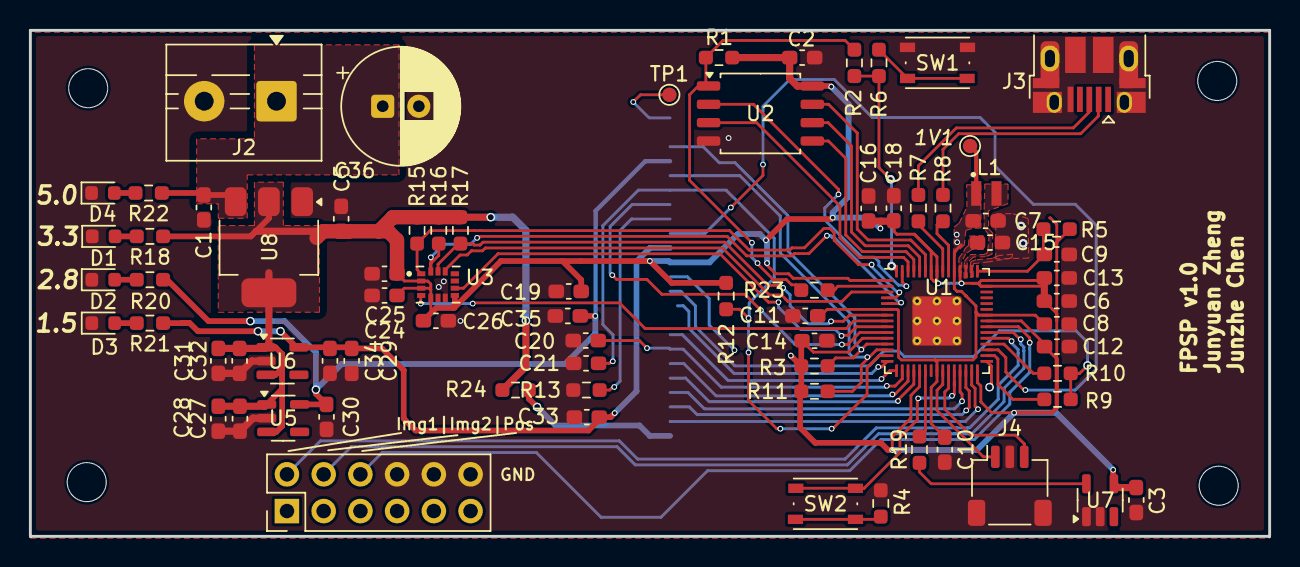
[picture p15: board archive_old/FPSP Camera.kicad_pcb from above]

Board: 4 copper layers, 85.7 x 35.0 mm, 80 parts (1 on the bottom side), 60 nets.

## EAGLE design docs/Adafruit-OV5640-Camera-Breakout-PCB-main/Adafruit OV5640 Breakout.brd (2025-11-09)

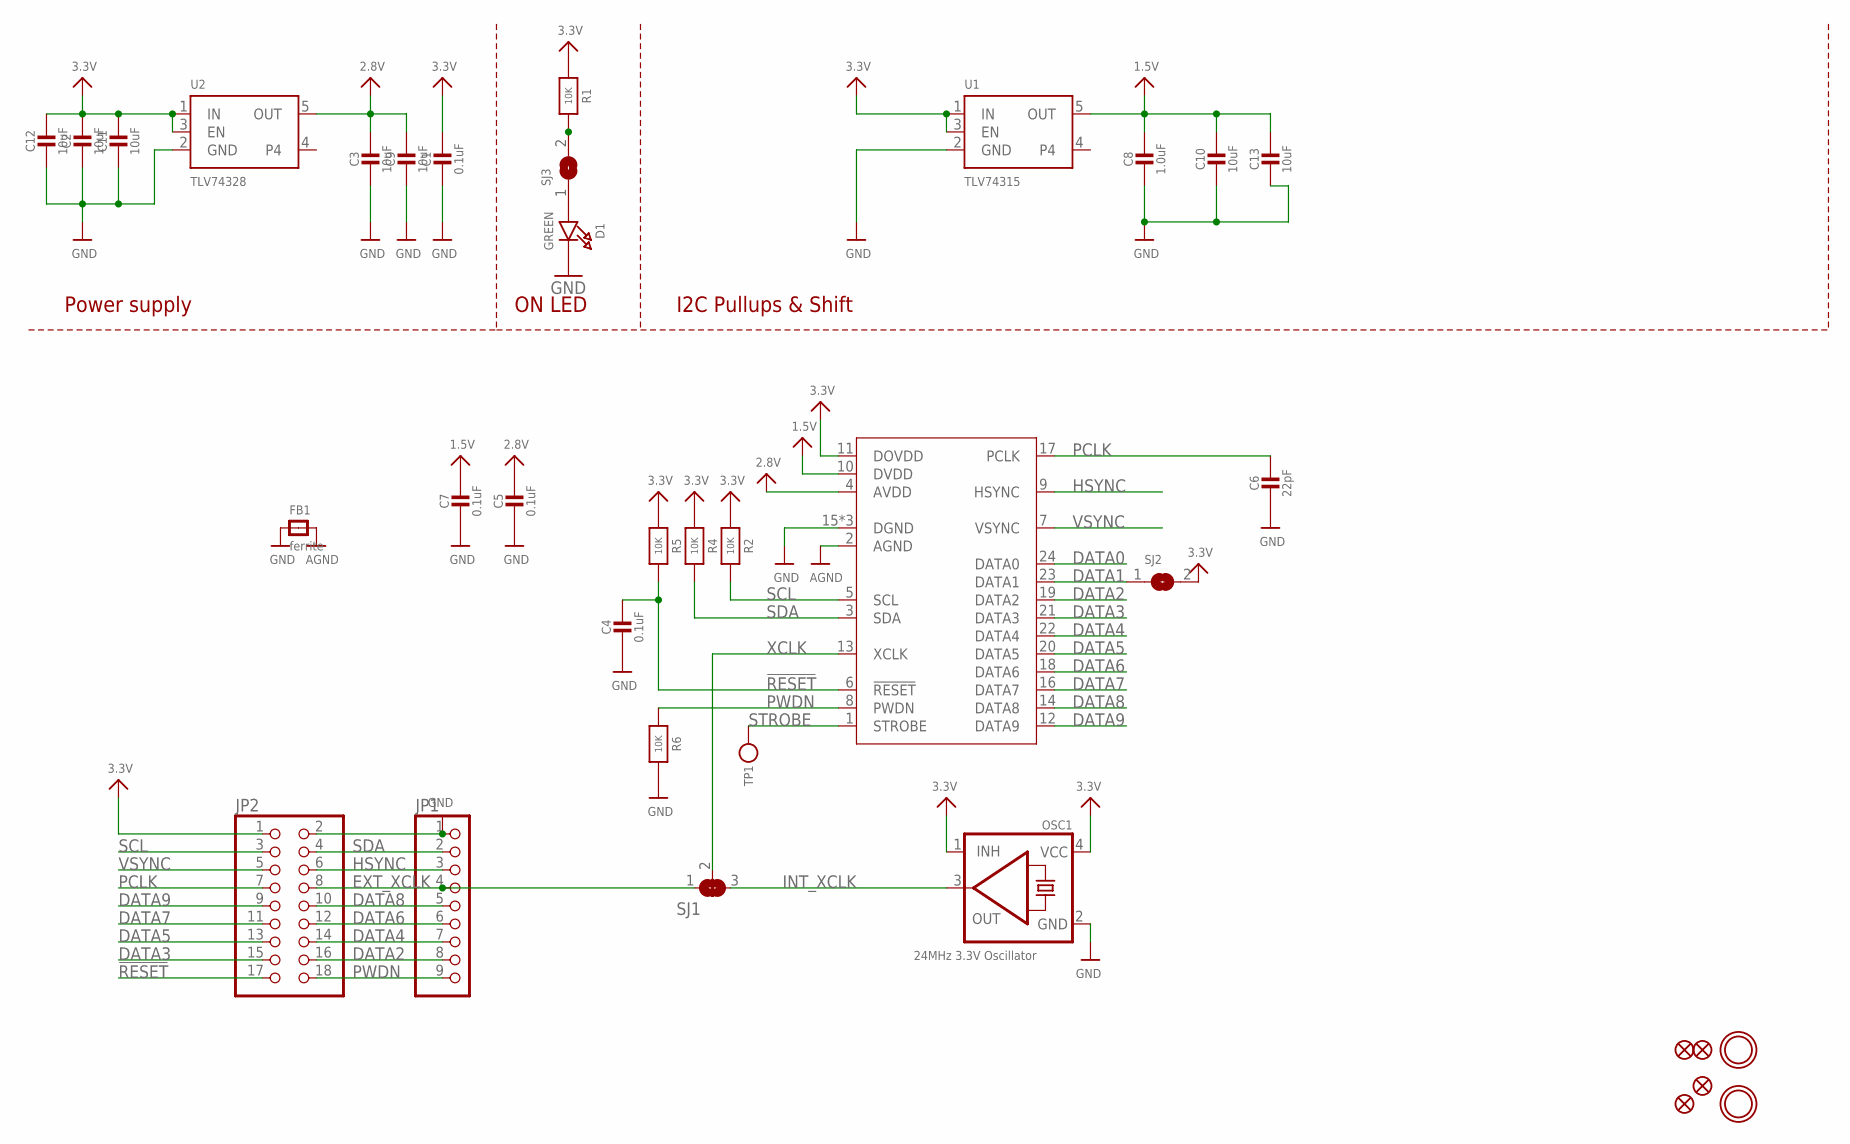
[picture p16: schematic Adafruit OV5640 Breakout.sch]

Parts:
C1, C4, C5, C7: 0.1uF; 0603-NO
C2, C3, C9, C10, C11, C12, C13: 10uF; 0805-NO
C6: 22pF; 0603-NO
C8: 1.0uF; 0603-NO
D1: GREEN; CHIPLED_0603_NOOUTLINE
FB1: ferrite; 0603-NO
FID1, FID2, FID3, FID4: FIDUCIAL_1MM
JP1: HEADER-1X970MIL; 1X09_ROUND_70
JP2: PINHD-2X9-BIG; 2X09-BIG
OSC1: 24MHz 3.3V Oscillator; OSC_3.2X2.5MM
R1, R2, R4, R5, R6: 10K; 0603-NO
SJ1: SOLDERJUMPER_2WAY; SOLDERJUMPER_2WAY_OPEN_NOPASTE
SJ2: SOLDERJUMPER; SOLDERJUMPER_ARROW_NOPASTE
SJ3: SOLDERJUMPERCLOSED; SOLDERJUMPER_CLOSEDWIRE
TP1: TESTPOINTROUND1.5MM; TESTPOINT_ROUND_1.5MM
U1: TLV74315; SOT23-5; JLC_ROTATION 0
U2: TLV74328; SOT23-5; JLC_ROTATION 0
U$1, U$17: MOUNTINGHOLE3.0THIN; MOUNTINGHOLE_3.0_PLATEDTHIN
X1: CAMERA_OV2640; OV2640FSL

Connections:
1.5V: C7.1, C8.1, C10.1, C13.1, U1.5 (OUT), X1.10 (DVDD)
2.8V: C3.1, C5.1, C9.1, U2.5 (OUT), X1.4 (AVDD)
3.3V: C1.1, C2.1, C11.1, C12.1, JP2.1, OSC1.1 (INH), OSC1.4 (VCC), R1.1, R2.1, R4.1, R5.1, SJ2.2, U1.1 (IN), U1.3 (EN), U2.1 (IN), U2.3 (EN), X1.11 (DOVDD)
!RESET: C4.1, JP2.17, R5.2, X1.6 (!RESET)
AGND: FB1.2, X1.2 (AGND)
DATA0: X1.24 (DATA0)
DATA1: SJ2.1, X1.23 (DATA1)
DATA2: JP1.8, JP2.16, X1.19 (DATA2)
DATA3: JP2.15, X1.21 (DATA3)
DATA4: JP1.7, JP2.14, X1.22 (DATA4)
DATA5: JP2.13, X1.20 (DATA5)
DATA6: JP1.6, JP2.12, X1.18 (DATA6)
DATA7: JP2.11, X1.16 (DATA7)
DATA8: JP1.5, JP2.10, X1.14 (DATA8)
DATA9: JP2.9, X1.12 (DATA9)
EXT_XCLK: JP1.4, JP2.8, SJ1.1
GND: C1.2, C2.2, C3.2, C4.2, C5.2, C6.2, C7.2, C8.2, C9.2, C10.2, C11.2, C12.2, C13.2, D1.C, FB1.1, JP1.1, JP2.2, OSC1.2 (GND), R6.2, U1.2 (GND), U2.2 (GND), X1.15 (DGND), X1.SPRT1 (DGND), X1.SPRT2 (DGND)
HSYNC: JP1.3, JP2.6, X1.9 (HSYNC)
INT_XCLK: OSC1.3 (OUT), SJ1.3
unnamed: R1.2, SJ3.2
unnamed: D1.A, SJ3.1
PCLK: C6.1, JP2.7, X1.17 (PCLK)
PWDN: JP1.9, JP2.18, R6.1, X1.8 (PWDN)
SCL: JP2.3, R2.2, X1.5 (SCL)
SDA: JP1.2, JP2.4, R4.2, X1.3 (SDA)
STROBE: TP1.P$1, X1.1 (STROBE)
VSYNC: JP2.5, X1.7 (VSYNC)
XCLK: SJ1.2, X1.13 (XCLK)

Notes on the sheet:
I2C Pullups & Shift
ON LED
Power supply

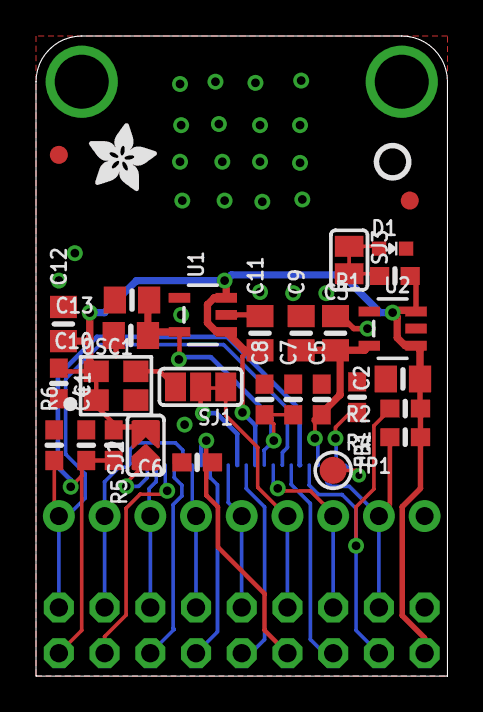
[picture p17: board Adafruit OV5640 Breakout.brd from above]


Board: 2 copper layers, 22.9 x 35.6 mm, 64 parts (27 on the bottom side), 27 nets.

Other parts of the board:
PLABEL0: PLABEL0
PLABEL1: PLABEL1
PLABEL2: PLABEL2
PLABEL3: PLABEL3
PLABEL4: PLABEL4
PLABEL5: PLABEL5
PLABEL6: PLABEL6
PLABEL7: PLABEL7
PLABEL8: PLABEL8
PLABEL9: PLABEL9
PLABEL10: PLABEL10
PLABEL11: PLABEL11
PLABEL12: PLABEL12
PLABEL13: PLABEL13
PLABEL14: PLABEL14
PLABEL15: PLABEL15
PLABEL16: PLABEL16
PLABEL17: PLABEL17
PLABEL18: PLABEL18
PLABEL19: PLABEL19
PLABEL20: PLABEL20
PLABEL21: PLABEL21
PLABEL22: PLABEL22
PLABEL23: PLABEL23
PLABEL24: PLABEL24
PLABEL25: PLABEL25
U$22: ADAFRUIT_3.5MM
U$25: PCBFEAT-REV-040

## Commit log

2025-11-09 Schematics version 1
    [ASM330LHHXTR.step, Adafruit OV5640 Breakout.brd, Adafruit OV5640 Breakout.sch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]
2025-11-09 minor changes
    [FPSP Camera.kicad_sch]
2025-11-09 crystal changed to mems
    [ASM330LHHXTR.step, FPSP Camera.kicad_sch, RP2350_60QFN_minimal.kicad_pcb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]
2025-11-10 Hierarchical schematics implemented, with small minor bugs fixed.
    [FPSP Camera.kicad_sch, fpc_imu_sch.kicad_sch, fpc_io.kicad_sch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]
2025-11-10 discarded 24MHz crystal. ERC passed 1st time
    [fpc_imu_sch.kicad_sch, fpc_io.kicad_sch, fpc_mcu.kicad_sch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]
2025-11-21 updates in layout
    [FPSP Camera.kicad_pcb, fpc_imu_sch.kicad_sch, fpc_io.kicad_sch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]
2025-11-22 pcb update
    [FPSP Camera.kicad_pcb]
2025-11-22 finished the routing
    [FPSP Camera.kicad_pcb]
2025-11-22 update schematics - remove one decoupling cap
    [FPSP Camera.kicad_sch]
2025-11-22 layout details finalized for prototype
    [FPSP Camera.kicad_pcb]
2025-11-23 vital change to pin order of connector; RP2350 SMPS layout changed
    [FPSP Camera.kicad_pcb, fpc_io.kicad_sch, fpc_mcu.kicad_sch]
2025-11-23 Documantations updated
    [Adafruit OV5640 Breakout.brd, Adafruit OV5640 Breakout.sch]
2025-11-23 I have tried my best...
    [Adafruit OV5640 Breakout.brd, Adafruit OV5640 Breakout.sch, FPSP Camera - Copy.kicad_pcb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]
2025-11-23 Reassigned MCU Pinout
    [FPSP Camera.kicad_sch]
2025-11-23 IMU Changed to ICM-45686
    [FPSP Camera.kicad_sch]
2025-11-23 IMU Subsystem Change
    [FPSP Camera.kicad_sch]
2025-11-23 MCU pinout change
    [FPSP Camera.kicad_sch]
2025-11-23 Reannotated schematic
    [FPSP Camera.kicad_sch]
2025-11-23 update MCU layout (initial draft)
    [FPSP Camera.kicad_pcb, FPSP Camera.kicad_sch]
2026-06-20 GPIO_1 added
    [Connector_board.kicad_pcb, Connector_board.kicad_sch, FPSP Camera.kicad_pcb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]
2026-06-23 layout refined
    [FPSP Camera.kicad_pcb, FPSP Camera.kicad_sch]
2026-06-23 Rpi Buck layout refined
    [FPSP Camera.kicad_pcb, FPSP Camera.kicad_sch]
2026-06-23 push button added; IMU updated
    [BoM_overall.xlsx, FPSP Camera.kicad_pcb, FPSP Camera.kicad_sch]
2026-06-24 connector board pin order updated
    [Connector_board.kicad_pcb, Connector_board.kicad_sch, FPSP Camera.kicad_pcb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]
2026-06-29 new connector footprint updated
    [Connector_board.kicad_pcb, Connector_board.kicad_sch, FPSP Camera.kicad_pcb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]
2026-06-29 connector footprint swapped
    [Connector_board.kicad_pcb, Connector_board.kicad_sch, FPSP Camera.kicad_pcb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]
2026-06-30 LDOs replaced
    [FPSP Camera.kicad_pcb, FPSP Camera.kicad_sch]
2026-06-30 connector board layout tweaked
    [Connector_board.kicad_pcb]

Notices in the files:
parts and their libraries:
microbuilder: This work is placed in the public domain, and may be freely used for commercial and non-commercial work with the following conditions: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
